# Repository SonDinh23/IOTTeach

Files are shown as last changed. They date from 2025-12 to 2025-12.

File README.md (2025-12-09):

# IOTTeach

<div align="center">

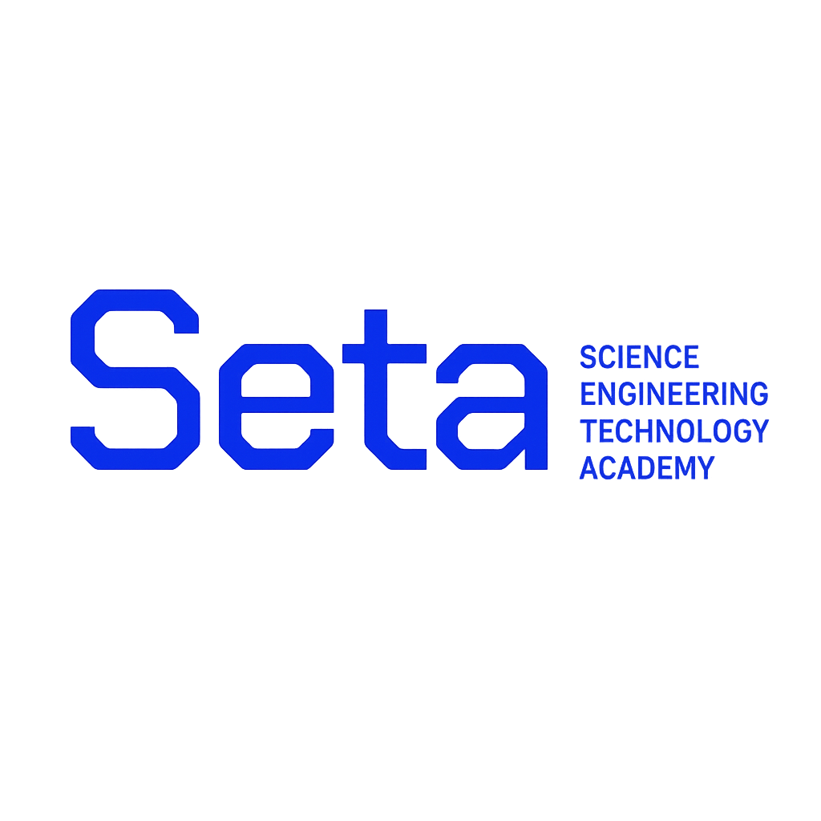
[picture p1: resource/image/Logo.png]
System diagram


### Modular IoT Learning & Test Kit

<p float="left">
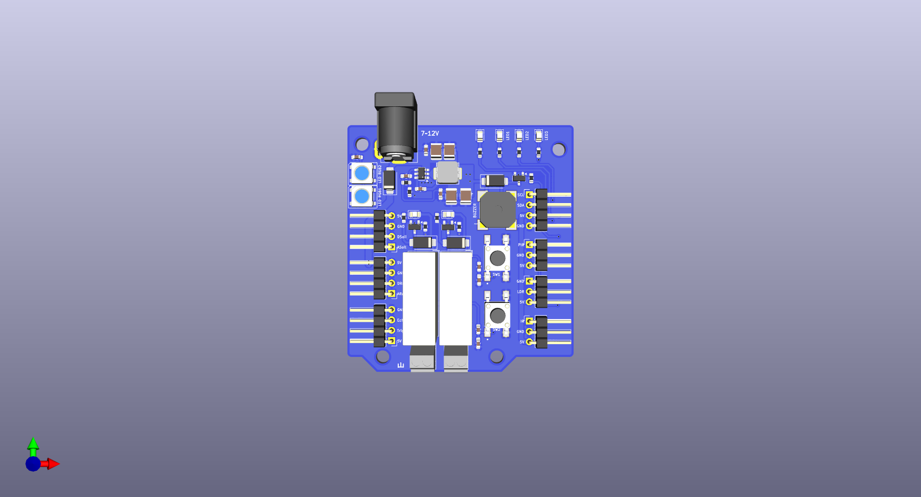
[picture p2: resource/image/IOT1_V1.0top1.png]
IOTTeach Top View

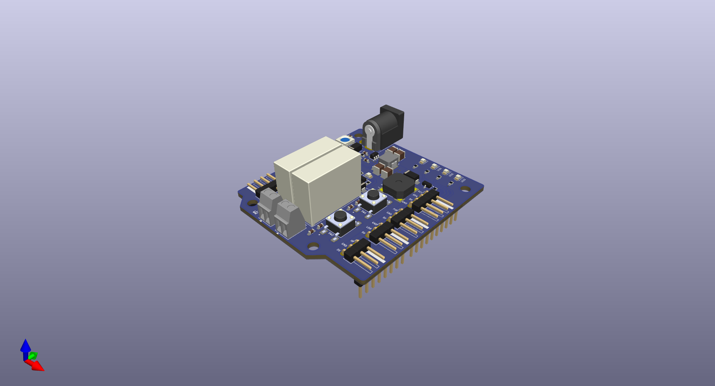
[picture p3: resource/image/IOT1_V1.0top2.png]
IOTTeach Top Angle

</p>

<p float="left">
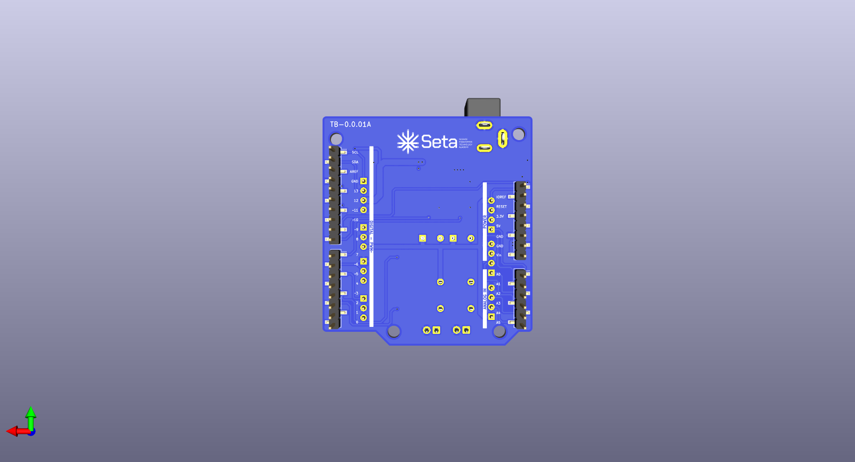
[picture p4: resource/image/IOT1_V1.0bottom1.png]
IOTTeach Bottom View

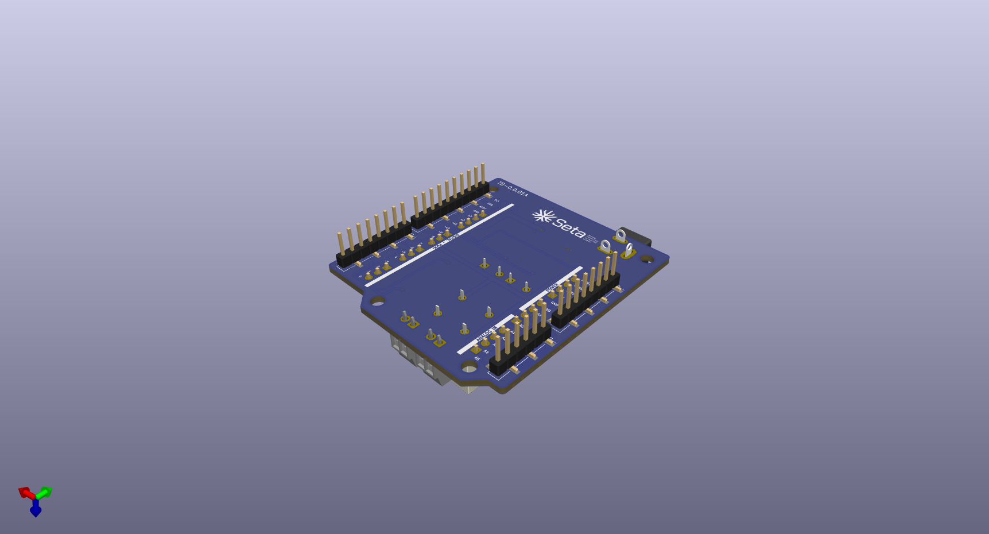
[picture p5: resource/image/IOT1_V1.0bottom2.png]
IOTTeach Bottom Angle

</p>

<sub>IOTTeach v1.0 — Top side (above) · Bottom side (below)</sub>

<br/><br/>





</div>

---

## Table of Contents

| Section | Description |
|---|---|
| About | Overview and intent |
| Hardware Overview | Technical summary |
| Key Features | Highlights and educational notes |
| Block Diagram | System block diagram |
| Getting Started | Quick start and assembly checklist |
| Lab Scenarios | Suggested exercises by level |
| License | License guidance |

---

## About

IOTTeach is a detachable plug-in kit designed for hands-on learning, quick hardware validation, and classroom labs. It exposes common peripherals (relays, RGB/status LEDs, buzzer) and standard 2.54 mm headers for power, analog, and digital lines so students and developers can prototype with any MCU or SBC without soldering a custom shield.

Design philosophy: Bring Your Own MCU — connect any microcontroller (ESP32, STM32, Arduino, Raspberry Pi Pico, etc.) using Dupont wires.

---

## Hardware Overview

| Component | Detail |
|:---:|:---|
| Power | DC jack (DC-005) + terminal block → TPS54202 buck converter → 3.3V/5V rail |
| GPIO Headers | Digital 1×10 · Digital 1×8 · Analog 1×6 · Power header (pitch 2.54 mm) |
| LED Indicators | 2× WS2812B RGB, discrete status LEDs (green/yellow/red) |
| Audio | Piezo buzzer (CMT-8530S-SMT), PWM capable |
| Relays | 2× Omron G5NB SPST relays, driven via SS8050 transistors |
| Protection | SS34 Schottky diodes for flyback, decoupling capacitors and input protection |
| Project Files | KiCad project and production outputs under `hardware/IOT1_V1.0/production/` |

### Core Components (summary)

• TPS54202DDC — Buck converter (3.3V, up to ~2A)

• WS2812B (×2) — Addressable RGB LEDs for visual feedback

• Omron G5NB Relays (×2) — SPST relays for switching experiments (observe safety limits)

• CMT-8530S-SMT — Piezo buzzer for audible signals

• SS8050 (×3) — NPN transistors as relay drivers

• SS34 (×4) — Schottky diodes for flyback/protection

---

## Key Features

### Modular & MCU-Agnostic

- Plug-and-play design: wire any MCU to the headers — no soldering required.
- Standard 2.54 mm pitch makes connecting and swapping modules fast and reliable.

### Education-Focused Layout

- Clear, labeled headers and wide component spacing for easy probing with oscilloscopes and logic analyzers.
- Progressive learning path: LEDs → switches → buzzer → relays → RGB, enabling stepwise lab exercises.

### Fabrication-Ready

- Complete production artifacts included: BOM, pick-and-place, netlist and KiCad project files.
- Files are in `hardware/IOT1_V1.0/production/` for easy handoff to PCB fabs and assemblers.

---

## Block Diagram

```
                              ┌─────────────────────────────────────┐
                              │          IOTTeach Board             │
                              └─────────────────────────────────────┘
                                              │
        ┌───────────────────────────────────────────────────────────────────┐
        │                                                                   │
        ▼                                                                   ▼
┌───────────────┐                                               ┌───────────────┐
│  POWER INPUT  │                                               │   MCU SIDE    │
│───────────────│                                               │───────────────│
│ • DC Jack     │                                               │ • Digital I/O │
│ • Terminal    │──► TPS54202 ──► 3.3V/5V Rail ──►             │ • Analog In   │
│   Block       │       Buck                                    │ • Power       │
└───────────────┘                                               └───────┬───────┘
                                                                        │
        ┌───────────────────────────────────────────────────────────────┘
        │
        ▼
┌─────────────────────────────────────────────────────────────────────────────┐
│                              PERIPHERALS                                     │
├─────────────────┬─────────────────┬─────────────────┬───────────────────────┤
│   VISUAL        │   AUDIO         │   ACTUATORS     │   INPUTS              │
├─────────────────┼─────────────────┼─────────────────┼───────────────────────┤
│ • 2× WS2812B    │ • Piezo Buzzer  │ • 2× SPST Relay │ • 2× Tactile Switch   │
│ • Status LEDs   │   (PWM tone)    │   (5A/250VAC)   │                       │
│                 │                 │ • SS34 Flyback  │                       │
└─────────────────┴─────────────────┴─────────────────┴───────────────────────┘
```

---

## Getting Started

### Prerequisites

- KiCad 7+ to view or edit the PCB project
- Any MCU board (ESP32, Arduino, STM32 Nucleo, Raspberry Pi Pico, etc.)
- Dupont jumper wires (Female-Female or Male-Female)

### Quick Start

```powershell
# Clone repository
git clone https://github.com/SonDinh23/IOTTeach.git
cd IOTTeach

# Open the KiCad project:
# File → Open Project → hardware/IOT1_V1.0/IOT1_V1.0.kicad_pro
```

### Recommended Assembly Order

1. Power stage: TPS54202, inductor, input/output capacitors, SS34 diodes
2. Install pin headers (all GPIO/power headers)
3. Passive components (resistors, caps)
4. Semiconductors (transistors, diodes, LEDs)
5. Modules and larger components (relays, buzzer, WS2812B)
6. Connectors and switches (DC jack, terminal blocks)

### First Power-On Checklist

- Verify no short between VCC and GND before powering
- Apply input power via DC jack (7–12 V recommended)
- Measure output rail (3.3V or 5V depending on configuration)
- Confirm power indicator LED lights up
- Connect MCU and run a basic LED blink test

---

## Lab Scenarios (Suggested Exercises)

### Level 1 — Beginner

- LED Blink: control a status LED (digital output)
- Button Read: read a tactile switch (digital input, pull-up)
- Buzzer Tone: generate tones using PWM (basic PWM)

### Level 2 — Intermediate

- RGB Effects: drive WS2812B for color patterns (NeoPixel protocol)
- Relay Timer: implement a timed relay control routine (timers/state machine)
- LED Patterns: create multi-LED sequences and animations (arrays/loops)

### Level 3 — Advanced

- Alarm System: integrate buzzer, RGB, and relay for a simulated alarm
- Power Profiling: measure board current under different loads (instrumentation)
- Remote Control: connect an MCU with Wi-Fi/BLE to control relays (networking)

---

## License

This project is presented as Open Hardware. Please add a specific license (for example, CERN-OHL, TAPR-OHL, or CC-BY-SA) to the repository before distributing manufacturing files or derivative works.

---

## Thanks

Thank you for exploring IOTTeach. Contributions, documentation improvements, and lab material suggestions are welcome — open an issue or submit a pull request.

<div align="center">

**[Back to Top](#iotteach)**

</div>

| Tính năng | Mô tả |
|---|---|
| **MCU Agnostic** | Tương thích ESP32, STM32, Arduino, Raspberry Pi Pico, v.v. |
| **Plug & Play** | Kết nối nhanh qua dây Dupont, không cần hàn |
| **Header chuẩn** | Pitch 2.54mm phổ biến, dễ tìm phụ kiện |

### 📚 Education-Focused

| Tính năng | Mô tả |
|---|---|
| **Clear Layout** | Component spacing rộng, dễ đo đạc oscilloscope |
| **Labeled Headers** | Đánh dấu rõ ràng chức năng từng chân |
| **Gradual Learning** | Từ LED → Switch → Buzzer → Relay → RGB |

### �icing Fabrication-Ready

| Tài liệu | Đường dẫn |
|---|---|
| **Schematic** | `hardware/IOT1_V1.0/IOT1_V1.0.kicad_sch` |
| **PCB Layout** | `hardware/IOT1_V1.0/IOT1_V1.0.kicad_pcb` |
| **3D Model** | `hardware/IOT1_V1.0/IOT1_V1.0.step` |
| **BOM** | `hardware/IOT1_V1.0/production/bom.csv` |
| **Pick & Place** | `hardware/IOT1_V1.0/production/positions.csv` |

---

## 📊 Block Diagram

```
                              ┌─────────────────────────────────────┐
                              │          IOTTeach Board             │
                              └─────────────────────────────────────┘
                                              │
        ┌───────────────────────────────────────────────────────────────────┐
        │                                                                   │
        ▼                                                                   ▼
┌───────────────┐                                               ┌───────────────┐
│  POWER INPUT  │                                               │   MCU SIDE    │
│───────────────│                                               │───────────────│
│ • DC Jack     │                                               │ • Digital I/O │
│ • Terminal    │──► TPS54202 ──► 3.3V/5V Rail ──►             │ • Analog In   │
│   Block       │       Buck                                    │ • Power       │
└───────────────┘                                               └───────┬───────┘
                                                                        │
        ┌───────────────────────────────────────────────────────────────┘
        │
        ▼
┌─────────────────────────────────────────────────────────────────────────────┐
│                              PERIPHERALS                                     │
├─────────────────┬─────────────────┬─────────────────┬───────────────────────┤
│   💡 VISUAL     │   🔊 AUDIO      │   ⚙️ ACTUATOR   │   🎛️ INPUT            │
├─────────────────┼─────────────────┼─────────────────┼───────────────────────┤
│ • 2× WS2812B    │ • Piezo Buzzer  │ • 2× SPST Relay │ • 2× Tactile Switch   │
│ • 2× LED Green  │   (PWM tone)    │   (5A/250VAC)   │                       │
│ • 1× LED Yellow │                 │ • SS34 Flyback  │                       │
│ • 3× LED Red    │                 │                 │                       │
└─────────────────┴─────────────────┴─────────────────┴───────────────────────┘
```

---

## 🚀 Getting Started

### Prerequisites

- **KiCad 7+** để xem/chỉnh sửa thiết kế
- **MCU board** bất kỳ (ESP32, Arduino Uno, STM32 Nucleo, etc.)
- **Dây Dupont** Female-Female hoặc Male-Female

### Quick Start

```bash
# 1. Clone repository
git clone https://github.com/SonDinh23/IOTTeach.git
cd IOTTeach

# 2. Mở project KiCad
# File → Open Project → hardware/IOT1_V1.0/IOT1_V1.0.kicad_pro
```

### Assembly Order (Khuyến nghị)

| Bước | Thành phần | Ghi chú |
|:----:|---|---|
| 1️⃣ | **Power Stage** | TPS54202, inductor L1, capacitors, SS34 diodes |
| 2️⃣ | **Headers** | Tất cả pin headers (J1-J14) |
| 3️⃣ | **Passives** | Resistors, capacitors còn lại |
| 4️⃣ | **Semiconductors** | Transistors SS8050, LEDs |
| 5️⃣ | **Modules** | Relays, buzzer, WS2812B |
| 6️⃣ | **Connectors** | DC jack, terminal blocks, switches |

### First Power-On Checklist

- [ ] Kiểm tra ngắn mạch giữa VCC-GND trước khi cấp nguồn
- [ ] Cấp nguồn qua DC jack (7-12V recommended)
- [ ] Đo điện áp output rail (3.3V hoặc 5V tùy config)
- [ ] LED power indicator sáng
- [ ] Kết nối MCU và test blink LED

---

## 🧪 Lab Scenarios

### 🟢 Level 1: Beginner

| Bài lab | Mô tả | Kỹ năng |
|---|---|---|
| **LED Blink** | Điều khiển LED đơn ON/OFF | Digital Output |
| **Button Read** | Đọc trạng thái nút nhấn | Digital Input, Pull-up |
| **Buzzer Tone** | Tạo âm thanh với tần số khác nhau | PWM basics |

### 🟡 Level 2: Intermediate

| Bài lab | Mô tả | Kỹ năng |
|---|---|---|
| **RGB Rainbow** | Hiệu ứng cầu vồng với WS2812B | NeoPixel protocol |
| **Relay Timer** | Bật/tắt relay theo thời gian | Timing, State machine |
| **Multi-LED Pattern** | Đèn chạy đuổi, hiệu ứng | Arrays, Loops |

### 🔴 Level 3: Advanced

| Bài lab | Mô tả | Kỹ năng |
|---|---|---|
| **Smart Alarm** | Hệ thống báo động: buzzer + LED + relay | System integration |
| **Power Profiling** | Đo dòng tiêu thụ ở các chế độ | Instrumentation |
| **IoT Control** | Điều khiển relay qua WiFi/BLE | Networking |

---

## 📜 License

Dự án này được phát hành dưới dạng **Open Hardware**.

> ⚠️ Vui lòng thêm license cụ thể (CERN-OHL, TAPR-OHL, hoặc CC-BY-SA) trước khi phân phối thiết kế.

---

## 🙏 Thanks

Cảm ơn bạn đã quan tâm đến **IOTTeach**!

Mọi góp ý về thiết kế, tài liệu hướng dẫn, hoặc ý tưởng bài thực hành đều được hoan nghênh.

<div align="center">

**[⬆ Back to Top](#iotteach)**

</div>

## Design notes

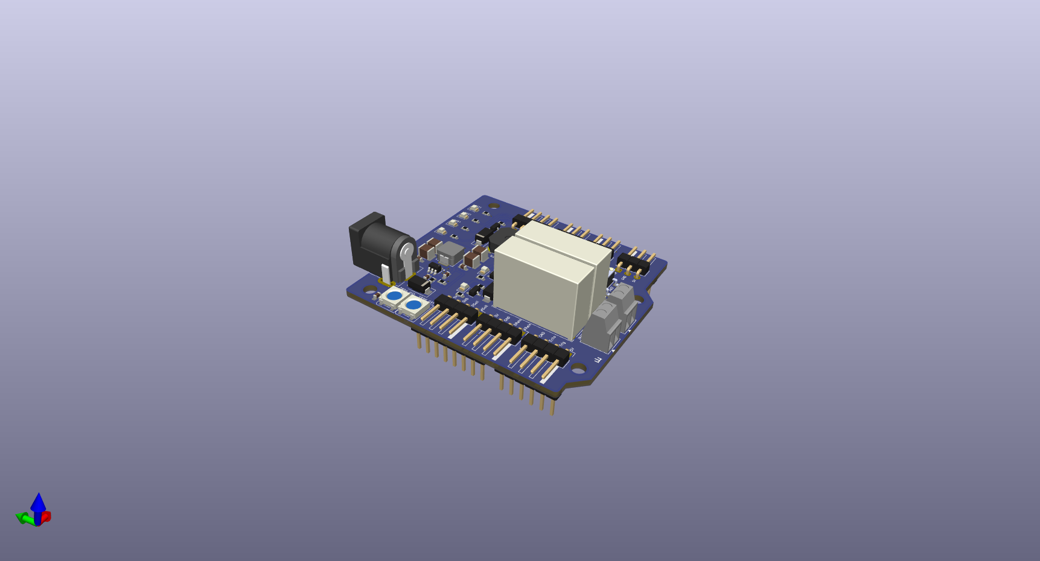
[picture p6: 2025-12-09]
hardware/IOT1_V1.0/IOT1_V1.0top3.png

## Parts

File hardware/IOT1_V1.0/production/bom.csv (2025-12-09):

Designator | Footprint | Quantity | Value | LCSC Part #
C10, C12, C17, C6, C8, C9 | 0603 | 6 | 100nF
C13, C15, C16, C5 | 1210 | 4 | C
C14 | 0603 | 1 | 68pF
D10, D14 | LED_WS2812B_PLCC4_5.0x5.0mm_P3.2mm | 2 | WS2812B
D11, D4 | 0805 | 2 | LED GREEN
D12 | 0805 | 1 | LED YELLOW
D13, D6, D7 | 0805 | 3 | LED RED
D3, D5, D8, D9 | D_SMA | 4 | SS34
J1 | PinHeader_1x10_P2.54mm_Vertical_SMD_Pin1Right | 1 | Digital
J10, J12, J13, J14 | PinHeader_1x04_P2.54mm_Horizontal | 4 | Conn_01x04_Pin
J11, J8, J9 | PinHeader_1x03_P2.54mm_Horizontal | 3 | Conn_01x03_Pin
J2 | PinHeader_1x08_P2.54mm_Vertical_SMD_Pin1Right | 1 | Digital
J3 | PinHeader_1x08_P2.54mm_Vertical_SMD_Pin1Right | 1 | Power
J4 | PinHeader_1x06_P2.54mm_Vertical_SMD_Pin1Right | 1 | Analog
J5, J7 | TerminalBlock_Xinya_XY308-2.54-2P_1x02_P2.54mm_Horizontal | 2 | Screw_Terminal_01x02
J6 | NINIGI_DC-005 | 1 | DC-005
K1, K2 | Relay_SPST_Omron_G5NB | 2 | G5NB
L1 | INDM5451X300N | 1 | IHLP2020CZER4R7M01
LS1 | CUI_CMT-8530S-SMT | 1 | CMT-8530S-SMT
Q1, Q2, Q3 | SOT-23 | 3 | SS8050
R10, R8, R9 | 0603 | 3 | 220R
R11 | 0603 | 1 | 100K
R12 | 0603 | 1 | 13.7K
R2, R4, R5 | 0603 | 3 | 1K
R22, R23 | 0603 | 2 | 10K
R3, R6, R7 | 0603 | 3 | 470R
SW1, SW2 | SW_4-1437565-2 | 2 | 4-1437565-2
U2 | SOT-23-6 | 1 | TPS54202DDC

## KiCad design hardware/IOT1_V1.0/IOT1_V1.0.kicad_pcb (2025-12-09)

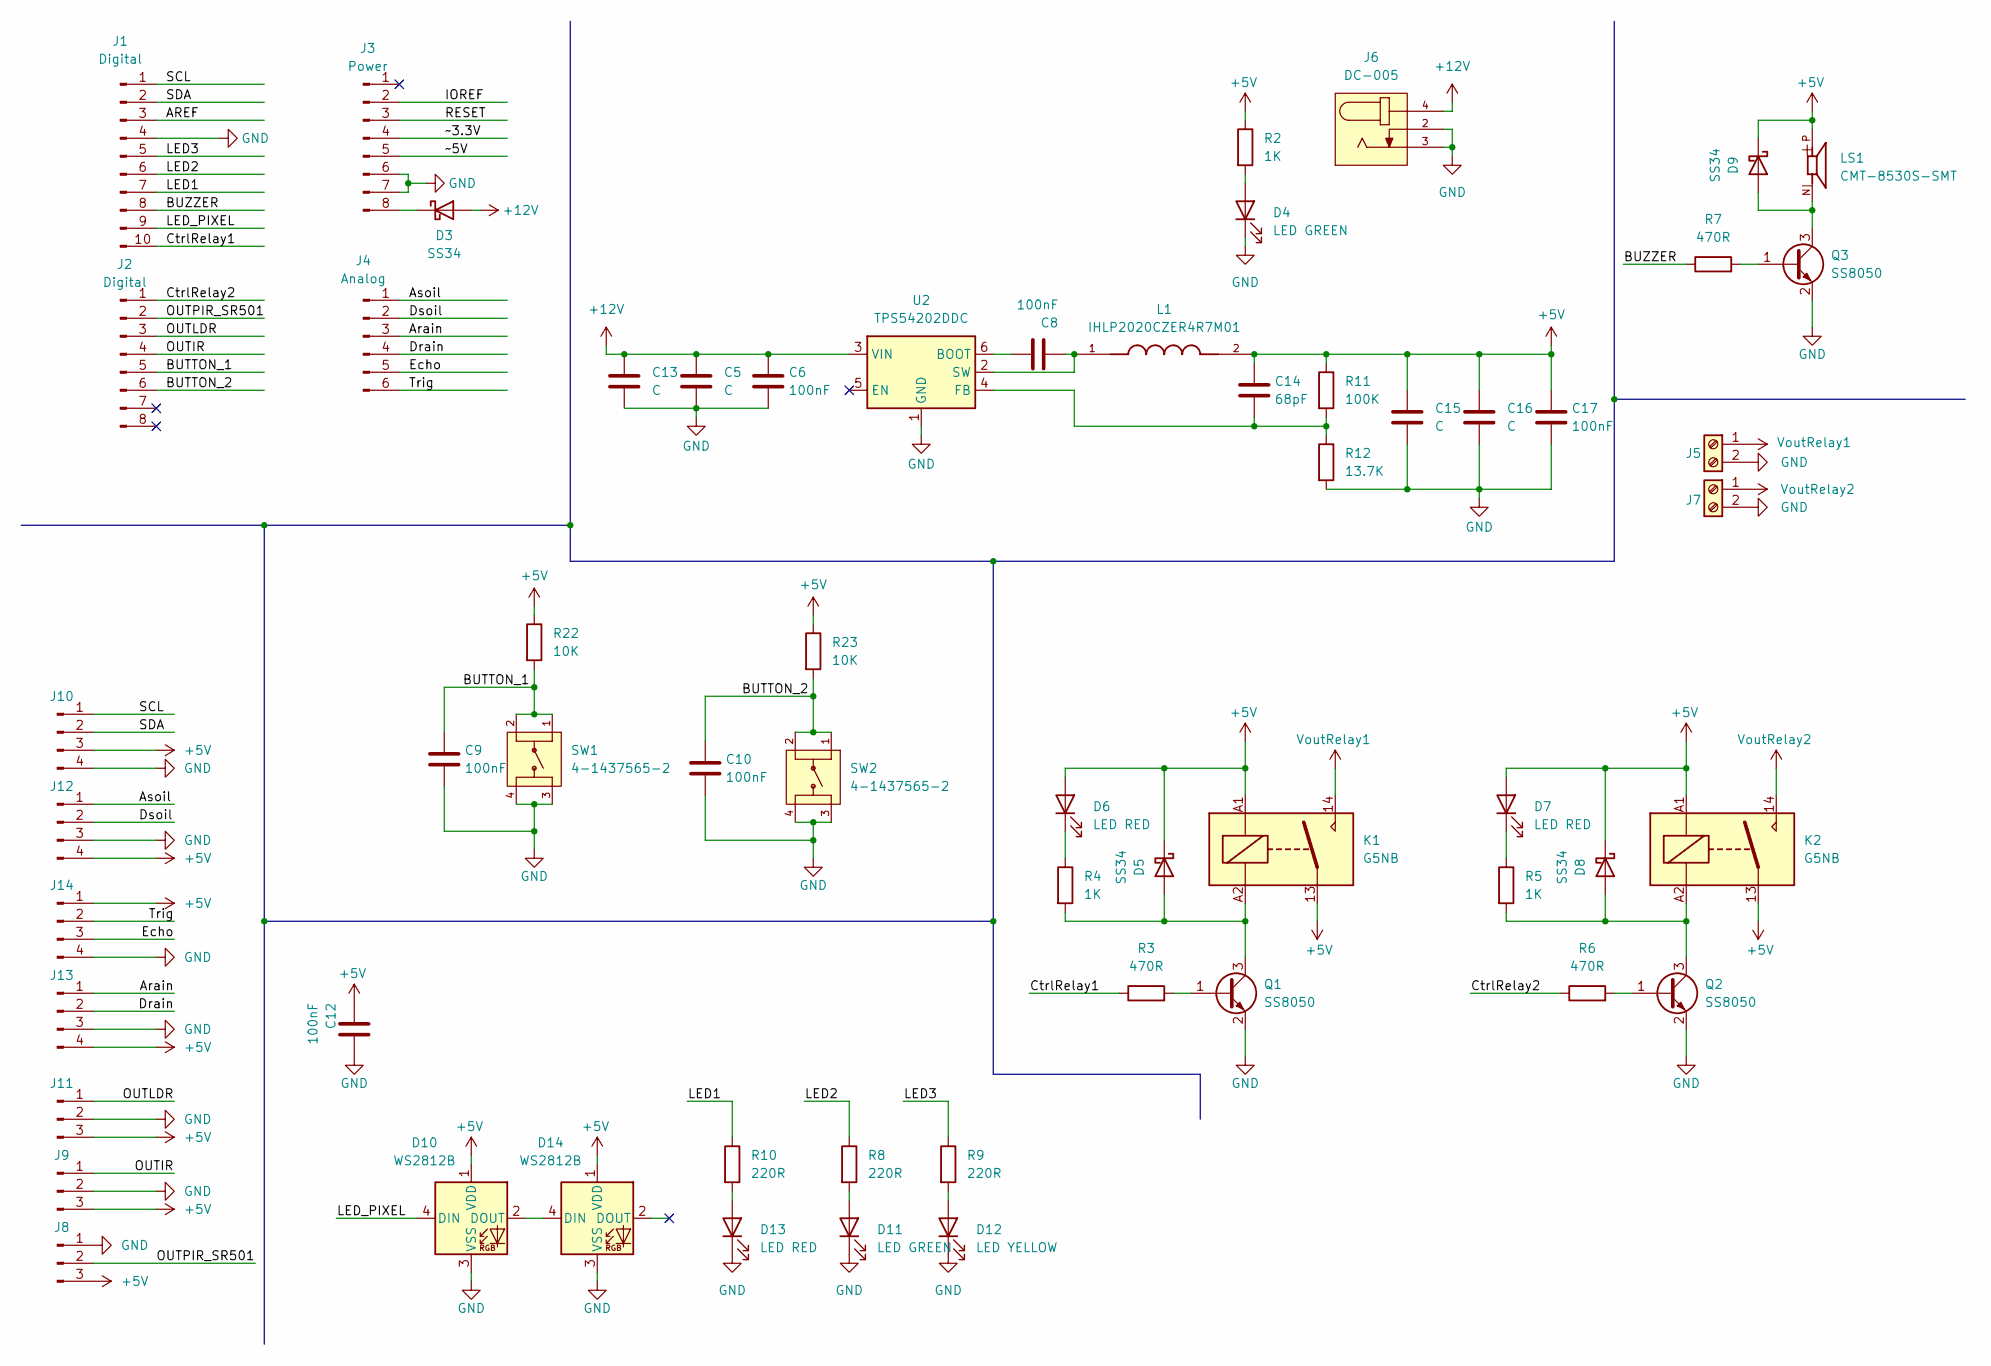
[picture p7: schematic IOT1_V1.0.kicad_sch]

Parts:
C5, C13, C15, C16: C; C_1210_3225Metric
C6, C8, C9, C10, C12, C17: 100nF; C_0603_1608Metric_Pad1.08x0.95mm_HandSolder
C14: 68pF; C_0603_1608Metric_Pad1.08x0.95mm_HandSolder
D3, D5, D8, D9: SS34; D_SMA
D4, D11: LED GREEN; LED_0805_2012Metric
D6, D7, D13: LED RED; LED_0805_2012Metric
D10, D14: WS2812B; LED_WS2812B_PLCC4_5.0x5.0mm_P3.2mm
D12: LED YELLOW; LED_0805_2012Metric
J1: Digital; PinHeader_1x10_P2.54mm_Vertical_SMD_Pin1Right
J2: Digital; PinHeader_1x08_P2.54mm_Vertical_SMD_Pin1Right
J3: Power; PinHeader_1x08_P2.54mm_Vertical_SMD_Pin1Right
J4: Analog; PinHeader_1x06_P2.54mm_Vertical_SMD_Pin1Right
J5, J7: Screw_Terminal_01x02; TerminalBlock_Xinya_XY308-2.54-2P_1x02_P2.54mm_Horizontal
J6: DC-005; NINIGI_DC-005
J8, J9, J11: Conn_01x03_Pin; PinHeader_1x03_P2.54mm_Horizontal
J10, J12, J13, J14: Conn_01x04_Pin; PinHeader_1x04_P2.54mm_Horizontal
K1, K2: G5NB; Relay_SPST_Omron_G5NB
L1: IHLP2020CZER4R7M01; INDM5451X300N; PARTREV 08-Jan-2024
LS1: CMT-8530S-SMT; CUI_CMT-8530S-SMT
Q1, Q2, Q3: SS8050; SOT-23
R2, R4, R5: 1K; R_0603_1608Metric
R3, R6, R7: 470R; R_0603_1608Metric
R8, R9, R10: 220R; R_0603_1608Metric
R11: 100K; R_0603_1608Metric
R12: 13.7K; R_0603_1608Metric
R22, R23: 10K; C_0603_1608Metric
SW1, SW2: 4-1437565-2; SW_4-1437565-2; PARTREV V
U2: TPS54202DDC; SOT-23-6

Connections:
+5V: C12.2, C14.1, C15.1, C16.1, C17.1, D5.1 (K), D6.2 (A), D7.2 (A), D8.1 (K), D9.1 (K), D10.1 (VDD), D14.1 (VDD), J8.3, J9.3, J10.3, J11.3, J12.4, J13.4, J14.1, K1.13, K1.A1, K2.13, K2.A1, L1.2, LS1.P, R2.1, R11.1, R22.1, R23.1
+12V: C5.1, C6.1, C13.1, D3.2 (A), J6.4, U2.3 (VIN)
/AREF: J1.3
/Arain: J4.3, J13.1
/Asoil: J4.1, J12.1
/BUTTON_1: C9.1, J2.5, R22.2, SW1.1, SW1.2
/BUTTON_2: C10.1, J2.6, R23.2, SW2.1, SW2.2
/BUZZER: J1.8, R7.1
/CtrlRelay1: J1.10, R3.1
/CtrlRelay2: J2.1, R6.1
/Drain: J4.4, J13.2
/Dsoil: J4.2, J12.2
/Echo: J4.5, J14.3
/IOREF: J3.2
/LED1: J1.7, R10.1
/LED2: J1.6, R8.1
/LED3: J1.5, R9.1
/LED_PIXEL: D10.4 (DIN), J1.9
/OUTIR: J2.4, J9.1
/OUTLDR: J2.3, J11.1
/OUTPIR_SR501: J2.2, J8.2
/RESET: J3.3
/SCL: J1.1, J10.1
/SDA: J1.2, J10.2
/Trig: J4.6, J14.2
/~3.3V: J3.4
/~5V: J3.5
GND: C5.2, C6.2, C9.2, C10.2, C12.1, C13.2, C15.2, C16.2, C17.2, D4.1 (K), D10.3 (VSS), D11.1 (K), D12.1 (K), D13.1 (K), D14.3 (VSS), J1.4, J3.6, J3.7, J5.2, J6.2, J6.3, J7.2, J8.1, J9.2, J10.4, J11.2, J12.3, J13.3, J14.4, Q1.2 (E), Q2.2 (E), Q3.2 (E), R12.2, SW1.3, SW1.4, SW2.3, SW2.4, U2.1 (GND)
unnamed: D3.1 (K), J3.8
unnamed: D4.2 (A), R2.2
unnamed: D5.2 (A), K1.A2, Q1.3 (C), R4.2
unnamed: D6.1 (K), R4.1
unnamed: D7.1 (K), R5.1
unnamed: D8.2 (A), K2.A2, Q2.3 (C), R5.2
unnamed: D9.2 (A), LS1.N, Q3.3 (C)
unnamed: D10.2 (DOUT), D14.4 (DIN)
unnamed: D11.2 (A), R8.2
unnamed: D12.2 (A), R9.2
unnamed: D13.2 (A), R10.2
unnamed: Q1.1 (B), R3.2
unnamed: Q2.1 (B), R6.2
unnamed: Q3.1 (B), R7.2
unnamed: C8.1, U2.6 (BOOT)
unnamed: C14.2, R11.2, R12.1, U2.4 (FB)
unnamed: C8.2, L1.1, U2.2 (SW)
VoutRelay1: J5.1, K1.14
VoutRelay2: J7.1, K2.14

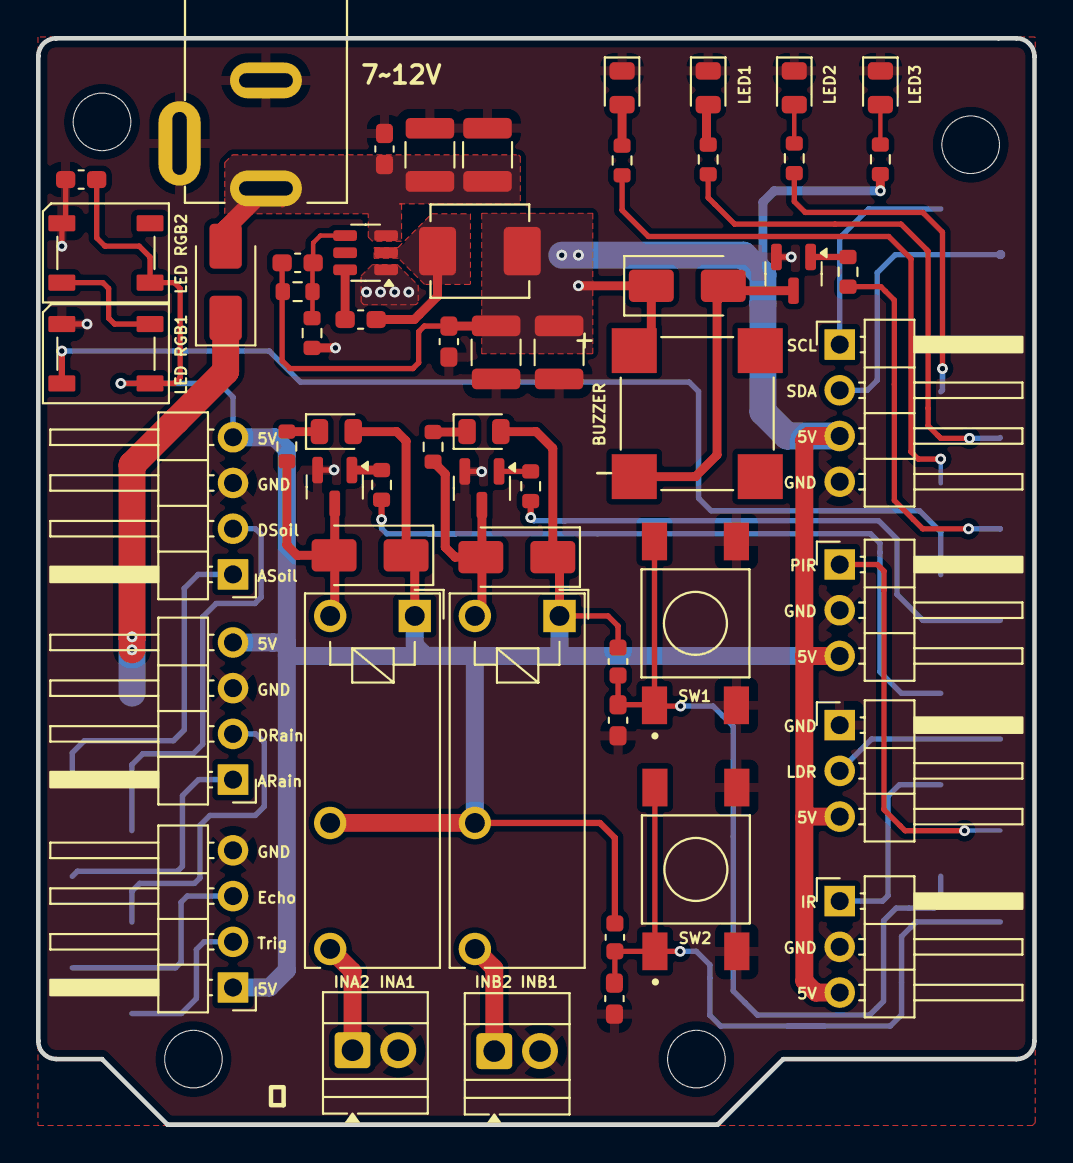
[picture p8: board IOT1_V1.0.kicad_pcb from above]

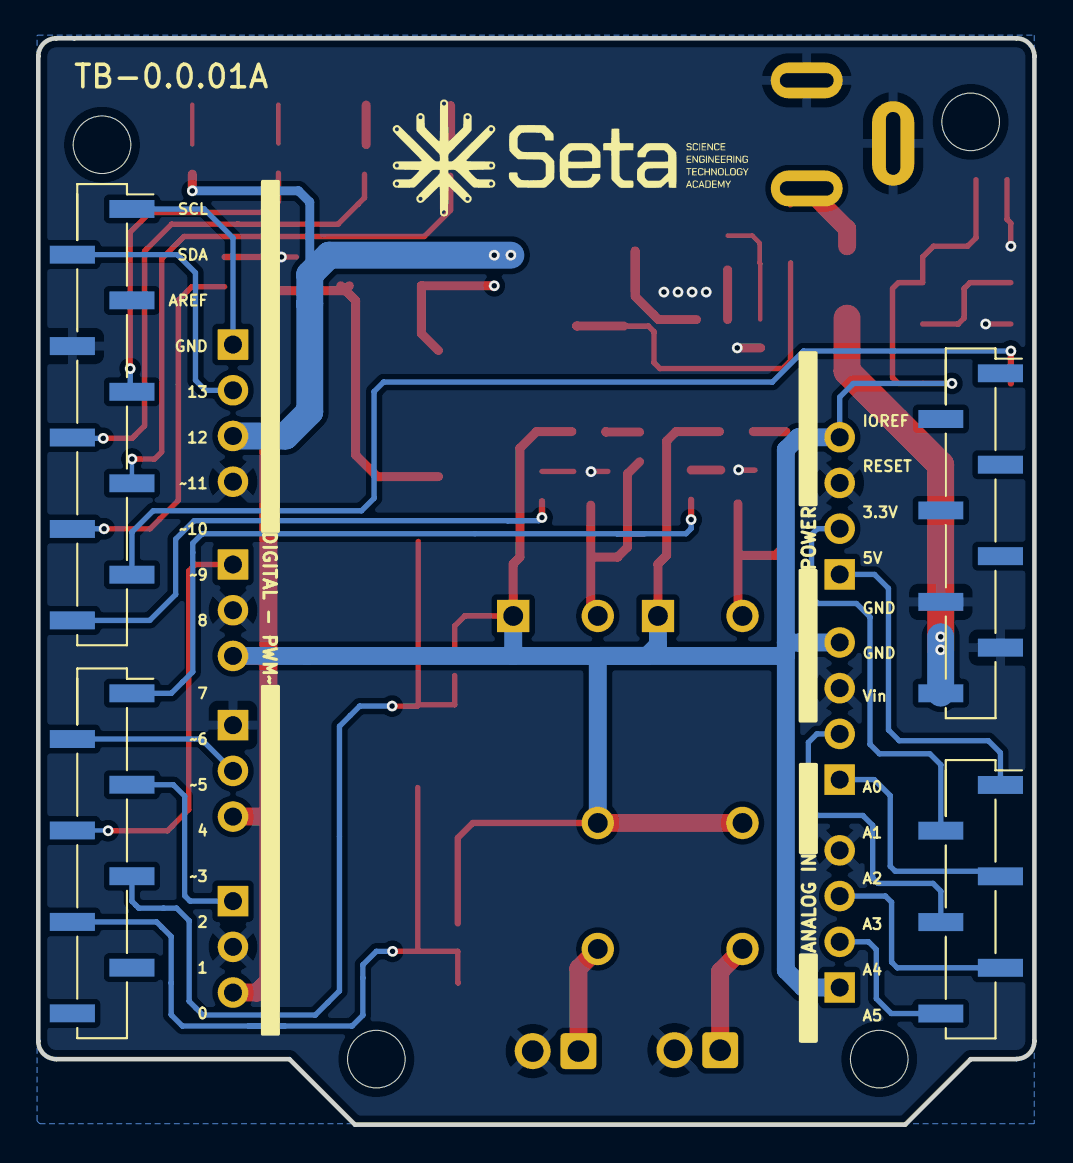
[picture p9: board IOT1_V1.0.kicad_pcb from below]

Board: 2 copper layers, 55.3 x 60.4 mm, 60 parts (4 on the bottom side), 42 nets.
